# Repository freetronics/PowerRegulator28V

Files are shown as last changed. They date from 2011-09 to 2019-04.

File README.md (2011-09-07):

Freetronics Power Regulator 28V
===============================
Copyright 2011 Freetronics Pty Ltd  
Freetronics site:  <www.freetronics.com>  
Freetronics email: <info@freetronics.com>  

Module to regulate power supplied on Power-over-Ethernet connection
down to 7Vdc for supply to the on-board voltage regulator in an
Arduino Uno, Freetronics Eleven, or other compatible board
using the Freetronics Ethernet Shield, or an EtherTen.

Features:

 * Adds Power-over-Ethernet "PD" (powered device) support to the
   Freetronics Ethernet shield.
 * Input voltage range 9-28Vdc.
 * Output voltage limited to 7V and fed to Arduino on-board voltage
   regulator via Ethernet shield for further regulation down to 5V.
 * Input protection diode to prevent damage due to reverse polarity.
 * Plugs directly onto Freetronics Ethernet Shield and EtherTen.
 * "Power on" LED.
 * Output voltage can be set to 5V for use as a general-purpose
   5V power supply module.

More information is available at:

  http://www.freetronics.com/pr28v

The "docs" folder within this repository includes a handy copy of the
schematic in PDF format and image(s) of the pcb.

INSTALLATION
------------
The design is saved as an EAGLE project. EAGLE PCB design software is
available from www.cadsoftusa.com free for non-commercial use. To use
this project download it and place the directory containing these files
into the "eagle" directory on your computer. Then open EAGLE and
navigate to Projects -> eagle -> PowerRegulator28V.

DISTRIBUTION
------------
The specific terms of distribution of this project are governed by the
license referenced below.

LICENSE
-------
Licensed under the TAPR Open Hardware License (www.tapr.org/OHL).
The "license" folder within this repository also contains a copy of
this license in plain text format.

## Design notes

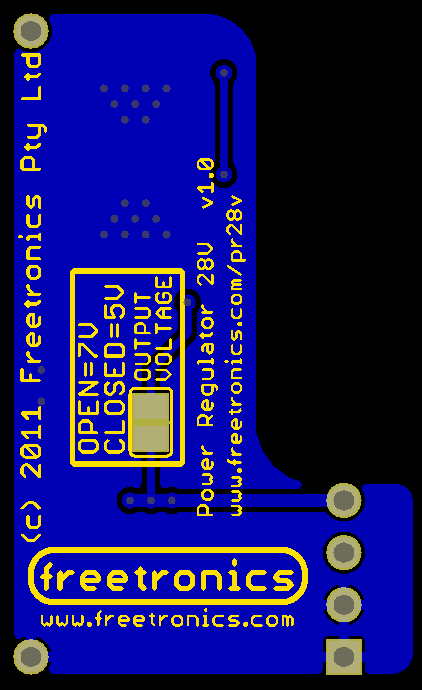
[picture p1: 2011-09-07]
docs/pr28v-bottom.png

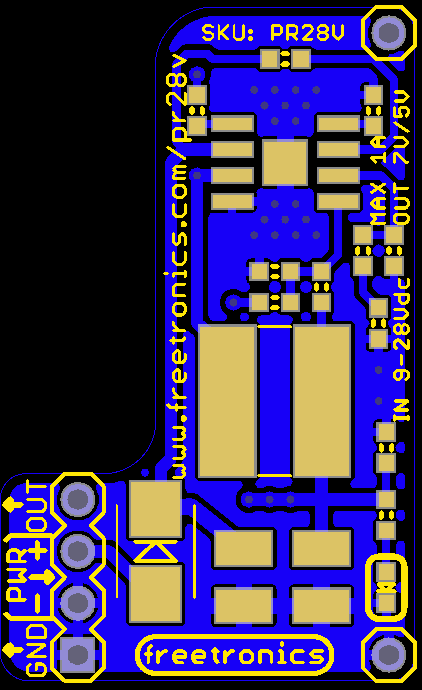
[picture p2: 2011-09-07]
docs/pr28v-top.png

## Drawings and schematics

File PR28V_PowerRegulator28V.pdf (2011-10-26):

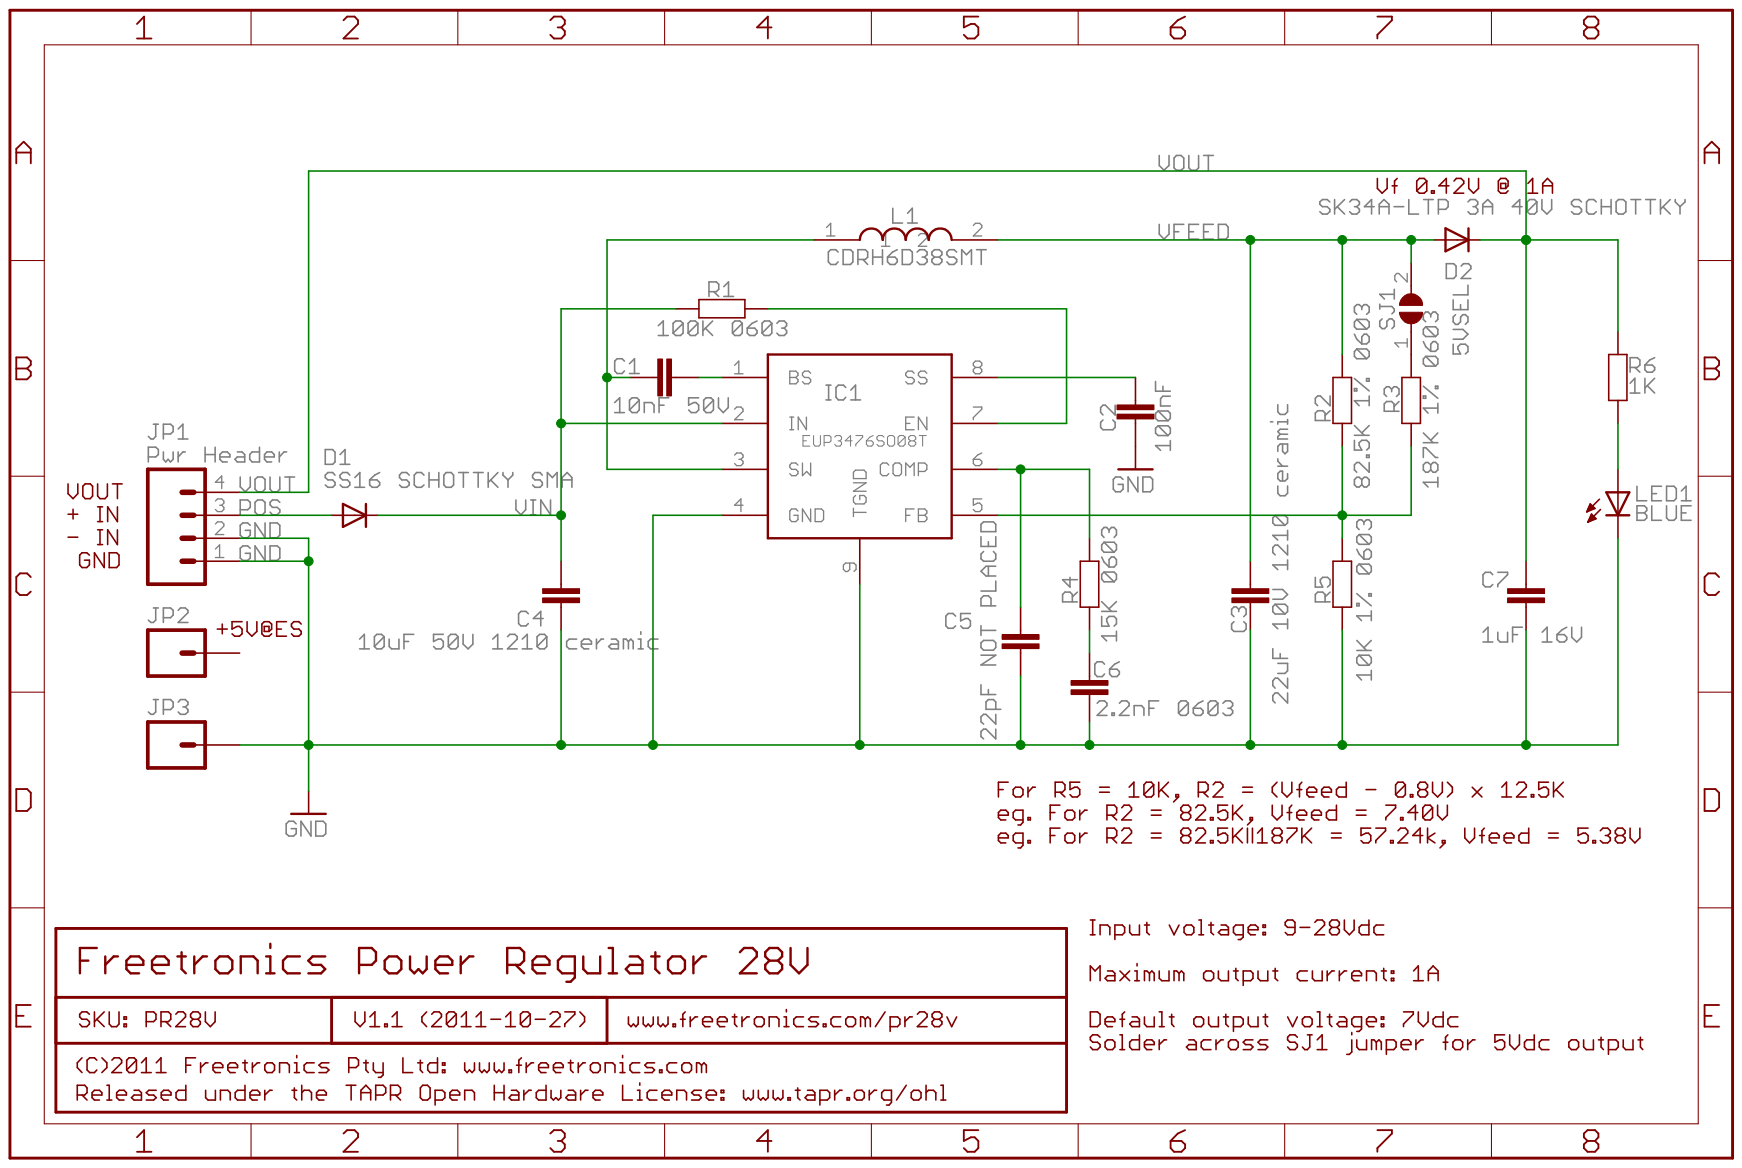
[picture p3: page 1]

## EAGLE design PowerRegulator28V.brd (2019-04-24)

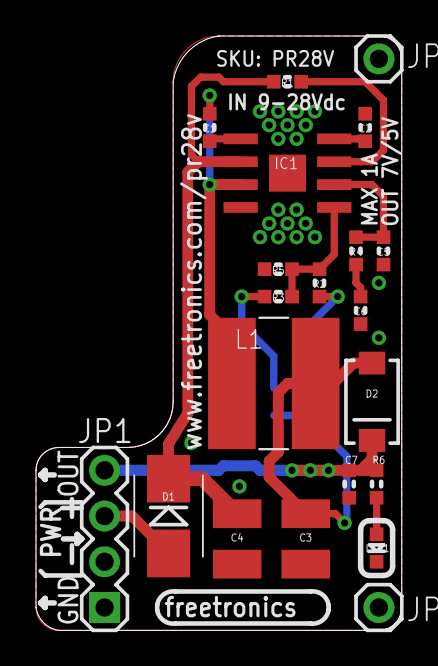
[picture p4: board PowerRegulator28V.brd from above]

Board: 2 copper layers, 20.3 x 33.0 mm, 22 parts (1 on the bottom side), 14 nets.

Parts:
C1: 10nF 50V; 0603
C2: 100nF; 0603
C3: 22uF 10V 1210 ceramic; C1210
C4: 10uF 50V 1210 ceramic; C1210
C5: 22pF NOT PLACED; 0603
C6: 2.2nF 0603; 0603
C7: 1uF 16V; 0603
D1: SS16 SCHOTTKY SMA; SMA-SMB-DIODE
D2: SK34A-LTP 3A 40V SCHOTTKY; SMA-DIODE
IC1: EUP3476SO08T; SO08T
JP1: Pwr Header; 1X04
JP2, JP3: 1X01
L1: CDRH6D38SMT; CDRH
LED1: BLUE; LED-0603
R1: 100K 0603; 0603
R2: 82.5K 1% 0603; 0603
R3: 187K 1% 0603; 0603
R4: 15K 0603; 0603
R5: 10K 1% 0603; 0603
R6: 1K; 0603
SJ1: 5VSEL; SJ

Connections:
GND: C2.1, C3.2, C4.2, C5.2, C6.2, C7.2, IC1.4, IC1.9, JP1.1, JP1.2, JP3.1, LED1.C, R5.1
unnamed: R3.1, SJ1.1
unnamed: IC1.7, R1.1
unnamed: IC1.5, R2.2, R3.2, R5.2
unnamed: C5.1, IC1.6, R4.2
unnamed: C6.1, R4.1
unnamed: C1.2, IC1.1
unnamed: C2.2, IC1.8
unnamed: C1.1, IC1.3, L1.1
unnamed: LED1.A, R6.2
POS: D1.A, JP1.3
VFEED: C3.1, D2.A, L1.2, R2.1, SJ1.2
VIN: C4.1, D1.C, IC1.2, R1.2
VOUT: C7.1, D2.C, JP1.4, R6.1

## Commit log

2011-08-19 Initial import
    [PoERegulator28V.brd, PoERegulator28V.sch]
2011-08-24 Updated reg footprint
    [PoERegulator28V.brd, PoERegulator28V.sch]
2011-08-25 Updated footprints for caps and inductor
    [PoERegulator28V.brd, PoERegulator28V.sch]
2011-08-26 General cleanups
    [PoERegulator28V.brd, PoERegulator28V.sch]
2011-08-28 Schematic notes and routing
    [PoERegulator28V.brd, PoERegulator28V.sch]
2011-08-28 Updated inductor overlay and product URL
    [PoERegulator28V.brd, PoERegulator28V.sch]
2011-08-28 Updated schematic labels and resistor values
    [PoERegulator28V.brd, PoERegulator28V.sch]
2011-08-29 Updated SO8 package
    [PoERegulator28V.brd, PoERegulator28V.sch]
2011-09-07 Minor routing and schematic changes
    [PoERegulator28V.brd, PoERegulator28V.sch]
2011-09-07 Renamed project files
    [PowerRegulator28V.brd, PowerRegulator28V.sch]
2011-09-07 Fixed silkscreen label
    [PowerRegulator28V.brd]
2011-09-30 Playing with output protection tweaks
    [PowerRegulator28V.brd, PowerRegulator28V.sch]
2011-10-13 v1.0 release
    [PowerRegulator28V.brd, PowerRegulator28V.sch]
2011-10-26 v1.1 production release
    [PowerRegulator28V.brd, PowerRegulator28V.sch]
2011-12-12 Schematic and Reference PDF renamed
2019-04-24 Designator improvement
    [PowerRegulator28V.brd]

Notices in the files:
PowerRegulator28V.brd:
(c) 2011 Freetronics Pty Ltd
